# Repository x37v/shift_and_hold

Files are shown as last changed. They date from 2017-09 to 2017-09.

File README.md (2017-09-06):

# Shift + Sample and Hold

This PCB is a 4 output 1 input sample and hold, 4 output trigger interface driven by a single analog input and shift register.
The boards are meant to cascade. The goal is to drive my drum-machine triggers and accent levels.

The sample and hold is based of this project:
http://www.supersynthesis.com/pages/lf398-sample-hold

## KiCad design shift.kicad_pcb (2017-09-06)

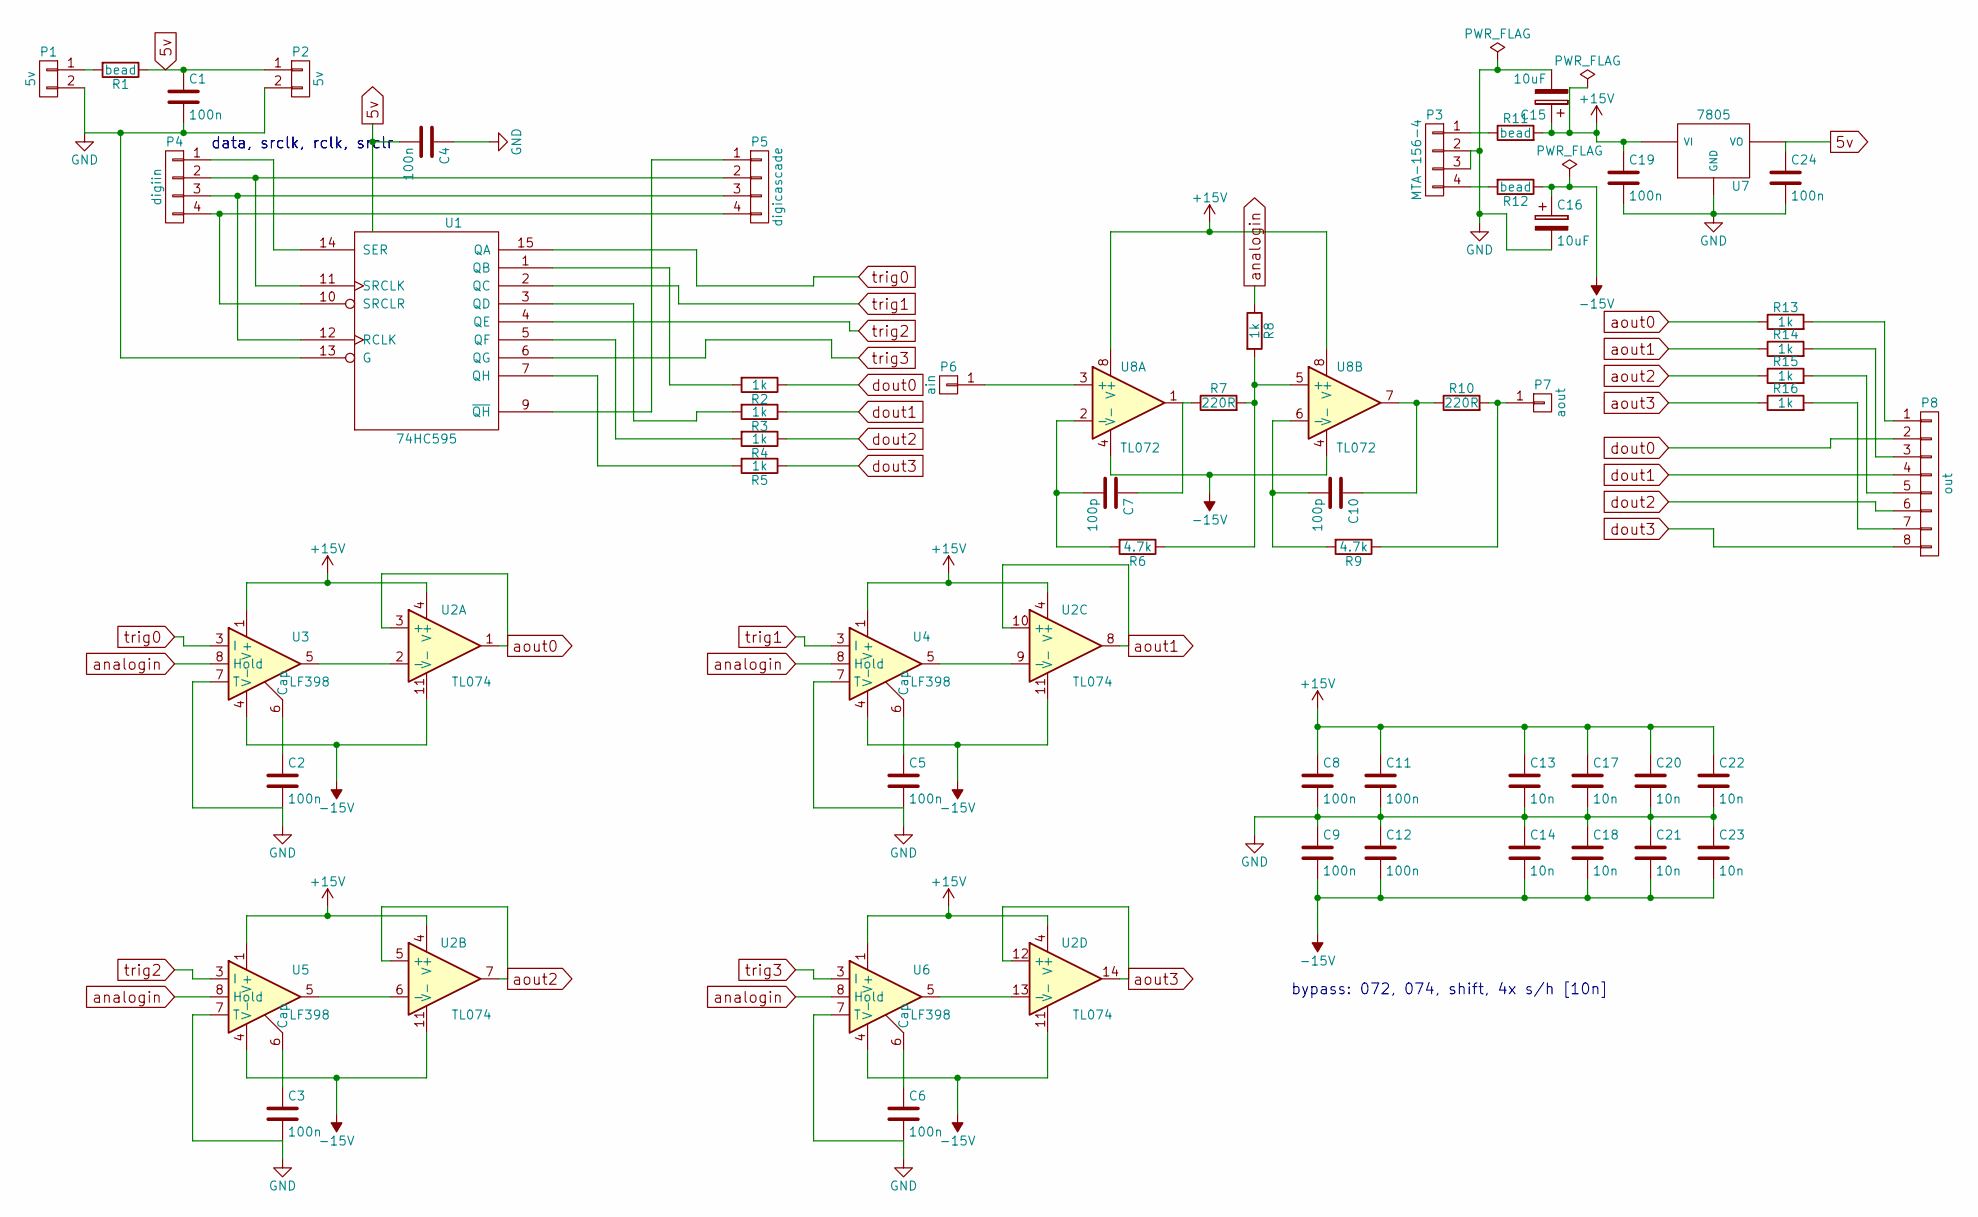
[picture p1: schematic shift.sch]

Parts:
C1, C4, C8, C9, C11, C12, C19, C24: 100n; C_Rect_L4_W2.5_P2.5
C2, C3, C5, C6: 100n; C_Rect_L7_W4.5_P5
C7, C10: 100p; C_Rect_L4_W2.5_P2.5
C13, C14, C17, C18, C20, C21, C22, C23: 10n; C_Rect_L4_W2.5_P2.5
C15, C16: 10uF; CP_Radial_Tantal_D7.0mm_P2.50mm
P1, P2: 5v; Pin_Header_Straight_1x02
P3: MTA-156-4
P4: digiin; Pin_Header_Straight_1x04
P5: digicascade; Pin_Header_Straight_1x04
P6: ain; Pin_Header_Straight_1x01
P7: aout; Pin_Header_Straight_1x01
P8: out; Pin_Header_Straight_1x08
R1, R11, R12: bead; Resistor_Vertical_RM5mm
R2, R3, R4, R5, R8, R13, R14, R15, R16: 1k; Resistor_Vertical_RM5mm
R6, R9: 4.7k; Resistor_Vertical_RM5mm
R7, R10: 220R; Resistor_Vertical_RM5mm
U1: 74HC595; DIP-16_W7.62mm_LongPads
U2: TL074; DIP-14_W7.62mm_Socket_LongPads
U3, U4, U5, U6: LF398; DIP-8_W7.62mm_LongPads
U7: 7805; TO-220_Vertical
U8: TL072; DIP-8_W7.62mm_LongPads

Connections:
5v: C1.1, C4.2, C24.1, P2.1, R1.1, U1.16 (VCC), U7.3 (VO)
+15V: C8.1, C11.1, C13.1, C15.1, C17.1, C19.1, C20.1, C22.1, R11.2, U2.4 (V+), U3.1 (V+), U4.1 (V+), U5.1 (V+), U6.1 (V+), U7.1 (VI), U8.8 (V+)
-15V: C9.2, C12.2, C14.2, C16.1, C18.2, C21.2, C23.2, R12.1, U2.11 (V-), U3.4 (V-), U4.4 (V-), U5.4 (V-), U6.4 (V-), U8.4 (V-)
GND: C1.2, C2.2, C3.2, C4.1, C5.2, C6.2, C8.2, C9.1, C11.2, C12.1, C13.2, C14.1, C15.2, C16.2, C17.2, C18.1, C19.2, C20.2, C21.1, C22.2, C23.1, C24.2, P1.2, P2.2, P3.2, P3.3, U1.8 (GND), U1.13 (G), U3.7 (T), U4.7 (T), U5.7 (T), U6.7 (T), U7.2 (GND)
unnamed: C2.1, U3.6 (Cap)
unnamed: C3.1, U5.6 (Cap)
unnamed: C5.1, U4.6 (Cap)
unnamed: C6.1, U6.6 (Cap)
unnamed: C7.1, R7.1, U8.1
unnamed: C7.2, R6.2, U8.2 (-)
unnamed: C10.1, R10.1, U8.7
unnamed: C10.2, R9.2, U8.6 (-)
unnamed: P1.1, R1.2
unnamed: P3.1, R11.1
unnamed: P3.4, R12.2
unnamed: P4.1, U1.14 (SER)
unnamed: P4.2, P5.2, U1.11 (SRCLK)
unnamed: P4.3, P5.3, U1.12 (RCLK)
unnamed: P4.4, P5.4, U1.10 (SRCLR)
unnamed: P5.1, U1.9 (~QH)
unnamed: P6.1, U8.3 (+)
unnamed: P7.1, R9.1, R10.2
unnamed: P8.1, R13.2
unnamed: P8.3, R14.2
unnamed: P8.5, R15.2
unnamed: P8.7, R16.2
unnamed: R2.2, U1.1 (QB)
unnamed: R3.2, U1.3 (QD)
unnamed: R4.2, U1.5 (QF)
unnamed: R5.2, U1.7 (QH)
unnamed: R6.1, R7.2, R8.2, U8.5 (+)
unnamed: U2.2 (-), U3.5
unnamed: U2.6 (-), U5.5
unnamed: U2.9 (-), U4.5
unnamed: U2.13 (-), U6.5
analogin: R8.1, U3.8 (Hold), U4.8 (Hold), U5.8 (Hold), U6.8 (Hold)
aout0: R13.1, U2.1, U2.3 (+)
aout1: R14.1, U2.8, U2.10 (+)
aout2: R15.1, U2.5 (+), U2.7
aout3: R16.1, U2.12 (+), U2.14
dout0: P8.2, R2.1
dout1: P8.4, R3.1
dout2: P8.6, R4.1
dout3: P8.8, R5.1
trig0: U1.15 (QA), U3.3 (I)
trig1: U1.2 (QC), U4.3 (I)
trig2: U1.4 (QE), U5.3 (I)
trig3: U1.6 (QG), U6.3 (I)

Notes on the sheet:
data, srclk, rclk, srclr
bypass: 072, 074, shift, 4x s/h [10n]

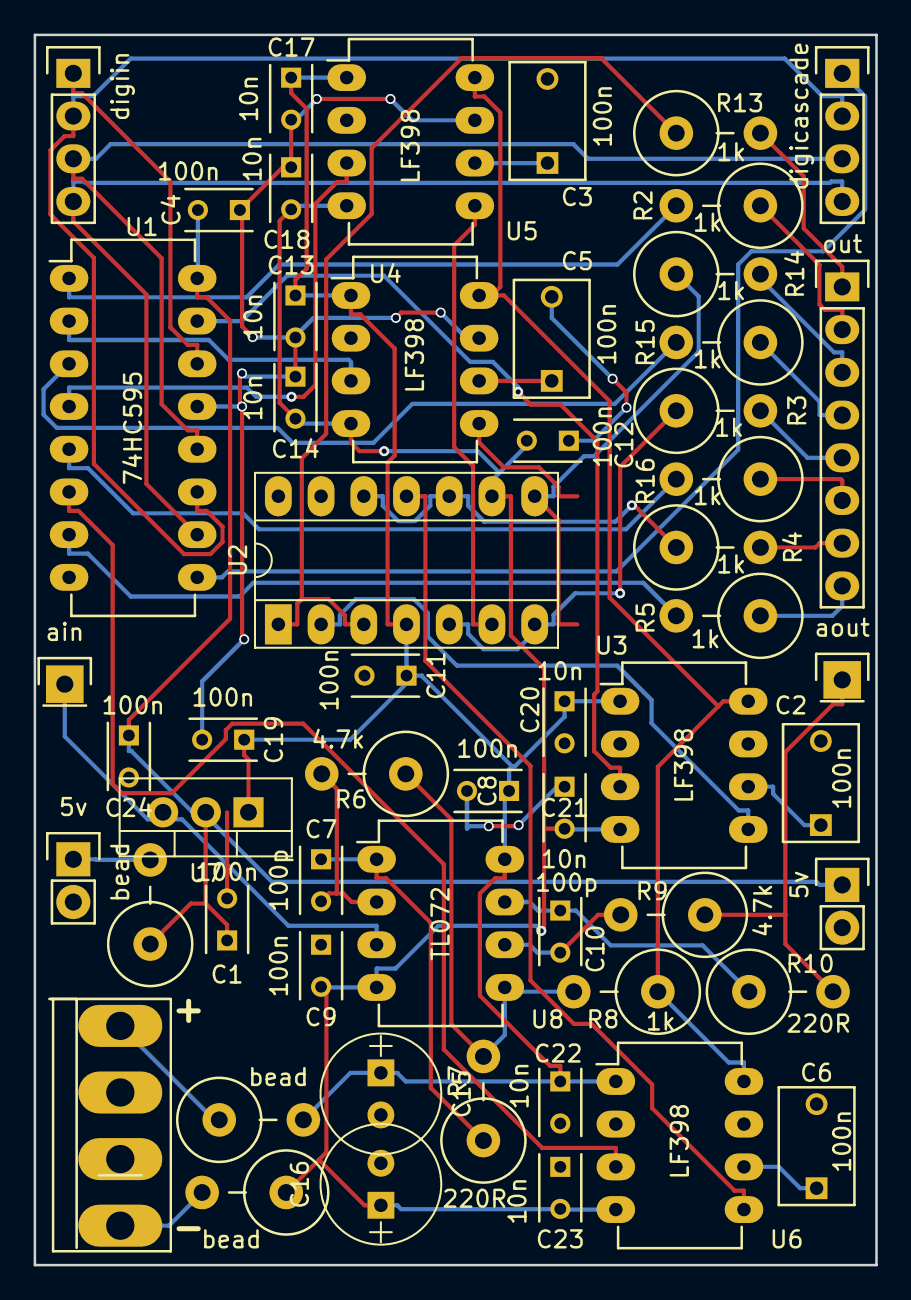
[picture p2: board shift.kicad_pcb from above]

Board: 2 copper layers, 50.0 x 73.2 mm, 56 parts (0 on the bottom side), 48 nets.

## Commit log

2016-10-26 real basic project setup
    [shift.kicad_pcb, shift.sch]
2016-10-28 updates... added correct header
    [shift.kicad_pcb, shift.sch]
2016-10-29 decouple caps, all layed out [i think] except routing
    [shift.kicad_pcb, shift.sch]
2016-10-29 auto routed and filled
    [shift.kicad_pcb]
2016-10-29 everything is hooked up, moved around too
    [shift.kicad_pcb, shift.sch]
2017-01-20 added some text
    [shift.kicad_pcb]
2017-01-20 attribution for sample and hold
2017-09-06 updated footprints for the bad 074 and vreg
    [shift.sch]
2017-09-06 updated caps to be bigger and added power flags
    [shift.sch]
2017-09-06 updated with new footprints, need to layout
    [shift.kicad_pcb]
